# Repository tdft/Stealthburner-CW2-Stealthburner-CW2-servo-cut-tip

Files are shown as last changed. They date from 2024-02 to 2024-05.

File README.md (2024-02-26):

# Stealthburner-CW2-Stealthburner-CW2-servo-cut-tip # klipper # mmu # ervf v2 #
Cutting tip of Stealthburner-CW2 servo steering gear

bilibili UID:450728302

by 3D造物主

1708151775972fbb961577cd52aac32a4a684aa6e033fde65

新版Happy-Hare可根据官方教程修改 https://github.com/moggieuk/Happy-Hare 进行修改

具体测试见哔哩哔哩【voron sb头舵机切刀测试】https://www.bilibili.com/video/BV19A4m157Jf?vd_source=c7e963c712fcfe6c78b672060f20e54b

https://github.com/tdft/Stealthburner-CW2-Stealthburner-CW2-servo-cut-tip/assets/52322373/de4dca90-7167-4381-bc9b-4ff3145389e5

本人对于所有事故不承担任何责任（包括但不限于触电、电器损坏等）

安装模块前务必断电拆机以免发生安全事故。

MG90S舵机待验证！！！

MG90S舵机待验证！！！

MG90S舵机待验证！！！
    
!!!!!!!!!!!!!!!!!!!!!!!!!!!!!!!!!!!!!!!
切刀臂不要加装弹簧，切刀回位依靠舵机！！！
！！！！！！！！！！！！！！！！！！！！！
    
安装前准备：

M3热熔螺母3*4*5若干

M3*12螺丝一颗

ES08MD舵机*1（MG90S）

电烙铁

cw2螺丝套装

舵机线预留100mm+

调试前拆掉切刀撞块，以免损坏部件


mmu/base/mmu_filametrix.cfg内的如下需根据机器大小、清理位置进行修改，仅参考

    ######################################
    
    #这应设置为从内部喷嘴尖端到切割刀片的距离，并用于上的计算
    #灯丝末端的最终位置(输出_停止_位置)和剩余灯丝片段大小(输出_剩余_灯丝)
    #供快乐野兔使用
    variable_blade_pos:37.5
    
    #切割前缩回的距离，这减少了浪费的细丝，但可能会造成堵塞
    #如果设置太大和/或轴端组件中有间隙
    #这必须小于“balde_pos”，即从喷嘴到刀具的距离
    variable_retract_length:32.5
    
    #销的位置，这应该是刀具架切刀时的位置
    #轻轻碰一下针
    variable_pin_loc_x:165 #22
    variable_pin_loc_y: 305
    
    #切割时的开始和结束位置
    #具体来说，不是通过移动到上面的销位置来进行切割，
    #我们沿X轴留有一个小的安全余量，以避免旅行时刮伤销
    #这也应该提供一小段距离，以便在按压销时产生一些动量
    variable_pin_park_x_dist:0 #9
    
    #刀具完全压缩时刀具架的位置
    #应留有较小的净空(例如，应稍大于0，或xmin值),以避免撞击工具架或台架
    variable_pin_loc_x_compressed: 165  #1
    
    #切削后缩回长度和速度，以便刀具可以回到原点位置
    variable_rip_length: 1			#收回以帮助手柄减压的距离(> = 0)
    variable_rip_speed: 750
    
    #将剩余的尖端从冷端推入热端。不能大于“回缩_长度”
    variable_pushback_length: 10
    variable_pushback_dwell_time: 0		#推后停留的时间
    ##########################################################################

安装

##########################################################################
1.
安装模块后需将mmu/base/mmu_hardware.cfg中的FILAMETRIX切丝机的可选龙门伺服系统[mmu_servo mmu_gantry_servo]
打开
参数仅供ES08MD数字舵机使用！！！！
    #用于FILAMETRIX切丝机的可选龙门伺服系统-
    #基本伺服PWM设置。如果这些值改变，那么为不同位置定义的角度也将改变
    #
    #仅当有机架伺服时取消注释
    
    #######################################
    
      [mmu_servo mmu_gantry_servo]
    pin:  EBBCan:PB9
    maximum_servo_angle: 180
    minimum_pulse_width: 0.0005
    maximum_pulse_width: 0.0025
    initial_angle: 130
    #######################################

2.
打开mmu/base/mmu_filametrix.cfg，启用机架伺服选项
    
    ########################################
    
    #如果安装了机架伺服选项，启用伺服并设置上下角度位置
    variable_gantry_servo_enabled: 1
    variable_gantry_servo_down_angle: -5  #即切料
    variable_gantry_servo_up_angle: 130
    
    ########################################

*3.选用
(直接复制替换掉mmu/base/mmu_filametrix.cfg内的参数)
    
    ########################################
    
    [gcode_macro _FILAMETRIX_GANTRY_SERVO_DOWN]
    description: Operate optional gantry servo operated pin
    gcode:
        {% if printer['gcode_macro _MMU_CUT_TIP']['gantry_servo_enabled'] > 0 %}
            {% set ANGLE = printer['gcode_macro _MMU_CUT_TIP']['gantry_servo_down_angle'] | float %}
            status_busy
            SET_SERVO SERVO=mmu_gantry_servo ANGLE={ANGLE}
            G4 P500
            _FILAMETRIX_GANTRY_SERVO_UP
            G4 P300
            SET_SERVO SERVO=mmu_gantry_servo ANGLE={ANGLE}
            G4 P200
            _FILAMETRIX_GANTRY_SERVO_UP
            SET_SERVO SERVO=mmu_gantry_servo ANGLE={ANGLE}
            G4 P600
            status_part_ready
        {% endif %}
    
    [gcode_macro _FILAMETRIX_GANTRY_SERVO_UP]
    description: Operate optional gantry servo operated pin
    gcode:
        {% if printer['gcode_macro _MMU_CUT_TIP']['gantry_servo_enabled'] > 0 %}
            {% set ANGLE = printer['gcode_macro _MMU_CUT_TIP']['gantry_servo_up_angle'] | float %}
            SET_SERVO SERVO=mmu_gantry_servo ANGLE={ANGLE}
        {% endif %}
        
    ########################################

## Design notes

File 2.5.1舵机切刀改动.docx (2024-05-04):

2.5.1

mmu/base/mmu_cut_tip.cfg内

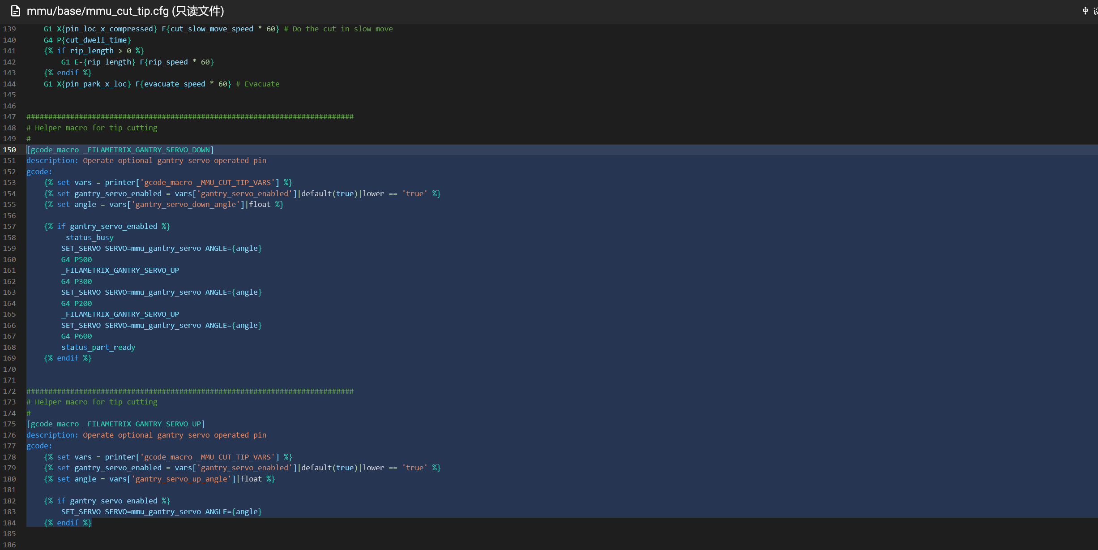
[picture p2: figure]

[gcode_macro _FILAMETRIX_GANTRY_SERVO_DOWN]

description: Operate optional gantry servo operated pin

gcode:

{% set vars = printer['gcode_macro _MMU_CUT_TIP_VARS'] %}

{% set gantry_servo_enabled = vars['gantry_servo_enabled']|default(true)|lower == 'true' %}

{% set angle = vars['gantry_servo_down_angle']|float %}

{% if gantry_servo_enabled %}

status_busy

SET_SERVO SERVO=mmu_gantry_servo ANGLE={angle}

G4 P500

_FILAMETRIX_GANTRY_SERVO_UP

G4 P300

SET_SERVO SERVO=mmu_gantry_servo ANGLE={angle}

G4 P200

_FILAMETRIX_GANTRY_SERVO_UP

SET_SERVO SERVO=mmu_gantry_servo ANGLE={angle}

G4 P600

status_part_ready

{% endif %}

# Helper macro for tip cutting

[gcode_macro _FILAMETRIX_GANTRY_SERVO_UP]

description: Operate optional gantry servo operated pin

gcode:

{% set vars = printer['gcode_macro _MMU_CUT_TIP_VARS'] %}

{% set gantry_servo_enabled = vars['gantry_servo_enabled']|default(true)|lower == 'true' %}

{% set angle = vars['gantry_servo_up_angle']|float %}

{% if gantry_servo_enabled %}

SET_SERVO SERVO=mmu_gantry_servo ANGLE={angle}

{% endif %}

mmu/base/mmu_hardware.cfg内

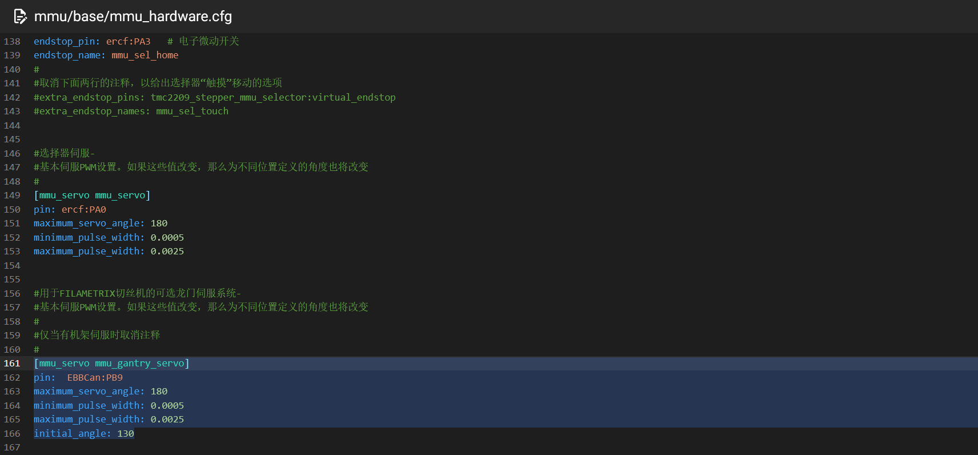
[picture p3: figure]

[mmu_servo mmu_gantry_servo]

pin: EBBCan:PB9 #按照自己舵机切刀引脚进行配置

maximum_servo_angle: 180

minimum_pulse_width: 0.0005

maximum_pulse_width: 0.0025

initial_angle: 130

mmu/base/mmu_parameters.cfg内

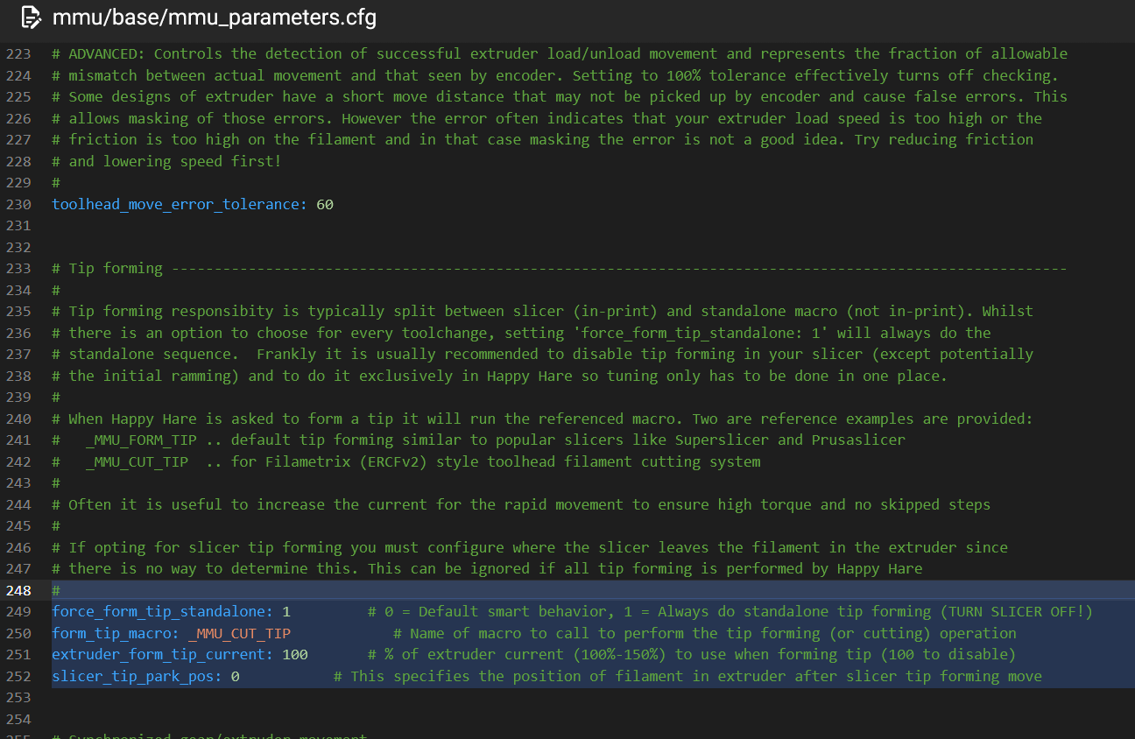
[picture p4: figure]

force_form_tip_standalone: 1 # 0 = Default smart behavior, 1 = Always do standalone tip forming (TURN SLICER OFF!)

form_tip_macro: _MMU_CUT_TIP # Name of macro to call to perform the tip forming (or cutting) operation

extruder_form_tip_current: 100 # % of extruder current (100%-150%) to use when forming tip (100 to disable)

slicer_tip_park_pos: 0 # This specifies the position of filament in extruder after slicer tip forming move

mmu/base/mmu_macro_vars.cfg内根据自己机器配置[gcode_macro _MMU_CUT_TIP_VARS]

参考：

[gcode_macro _MMU_CUT_TIP_VARS]

description: Happy Hare toolhead tip cutting macro configuration variables

gcode: # Leave empty

# Whether the toolhead tip cutting macro will return toolhead to initial

# position (usually wipetower) after the cut is complete. If using parking

# logic you may want to disable this and set 'park_after_form_tip: True'

variable_restore_position : True ; True = return to initial position, False = don't return

# Distance from the internal nozzle tip to the cutting blade. This dimension

# is based on your toolhead and should not be used for tuning

variable_blade_pos : 37.5 ; Distance in mm from internal nozzle tip

# Distance to retract prior to making the cut, this reduces wasted filament

# (left behind in extruder) but might cause clog if set too large and/or if

# there are gaps in the hotend assembly. This must be less than 'blade_pos'

variable_retract_length : 31.5 ; (5mm less than 'blade_pos' is a good starting point)

# Whether to perform a simple tip forming move after the initial retraction

# Enabling this adds some time to the cutting but gives some additional cooling

# time of molten filament and avoids potential clogging on some hotends

variable_simple_tip_forming : 1 ; True = Perform simple tip forming, False = skip

# This should be the position of the toolhead where the cutter arm just

# lightly touches the depressor pin

variable_pin_loc_xy : 280, 304 ; x,y coordinates of depressor pin

# This distance is added to 'pin_loc_x' to determine the starting position

# and to create a small saftely distance that aids in generating momentum

variable_pin_park_x_dist : 0 ; Distance in mm

# Position of the toolhead when the cutter is fully compressed. Should leave

# a small headroom (should be a bit larger than 0, or whatever xmin is) to

# avoid banging the toolhead or gantry

variable_pin_loc_x_compressed : 280 ; x coordinate

# Retract length and speed after the cut so that the cutter blade doesn't

# get stuck on return to origin position

variable_rip_length : 1 ; Distance in mm to retract to aid lever decompression (>= 0)

variable_rip_speed : 12 ; Speed mm/s

# Pushback of the remaining tip from the cold end into the hotend. This does

# not have to push back all the way, just sufficient to ensure filament

# fragment stays in hot end. Cannot be larger than 'retract_length'

variable_pushback_length : 10 ; Distance in mm

variable_pushback_dwell_time : 0 ; Time in ms to dwell after the pushback

# Speed related settings for tip cutting

# Note that if the cut speed is too fast, the steppers can lose steps.

# Therefore, for a cut:

# - We first make a fast move to accumulate some momentum and get the cut

# blade to the initial contact with the filament

# - We then make a slow move for the actual cut to happen

variable_travel_speed : 166 ; Speed mm/s

variable_cut_fast_move_speed : 33 ; Speed mm/s

variable_cut_slow_move_speed : 8 ; Speed mm/s

variable_evacuate_speed : 166 ; Speed mm/s

variable_cut_dwell_time : 50 ; Time in ms to dwell at the cut point

variable_cut_fast_move_fraction : 1.0 ; Fraction of the move that uses fast move

variable_extruder_move_speed : 50 ; Speed mm/s for all extruder movement

# Safety margin for fast vs slow travel. When traveling to the pin location

# we make a safer but longer move if we are closer to the pin than this

# specified margin. Usually setting these to the size of the toolhead

# (plus a small margin) should be good enough

variable_safe_margin_xy : 0, 0 ; Approx toolhead width +5mm, height +5mm)

# If gantry servo option is installed, enable the servo and set up and down

# angle positions

variable_gantry_servo_enabled : True ; True = enabled, False = disabled

variable_gantry_servo_down_angle: -5 ; Angle for when pin is deployed

variable_gantry_servo_up_angle : 130 ; Angle for when pin is retracted

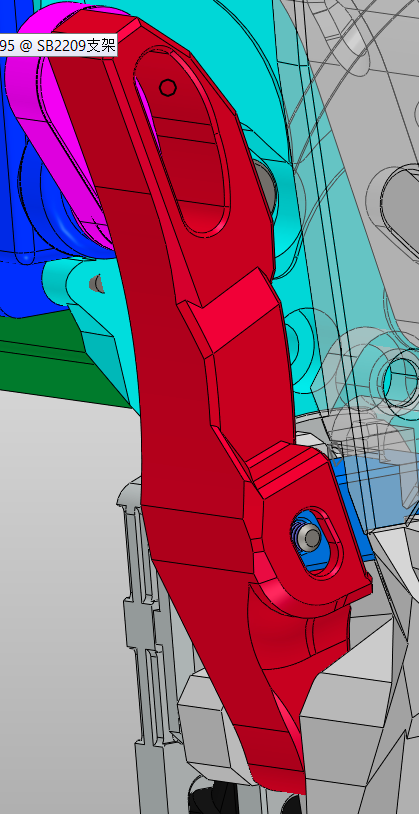
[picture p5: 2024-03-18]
stls/必打/2选1/切刀臂v2.png

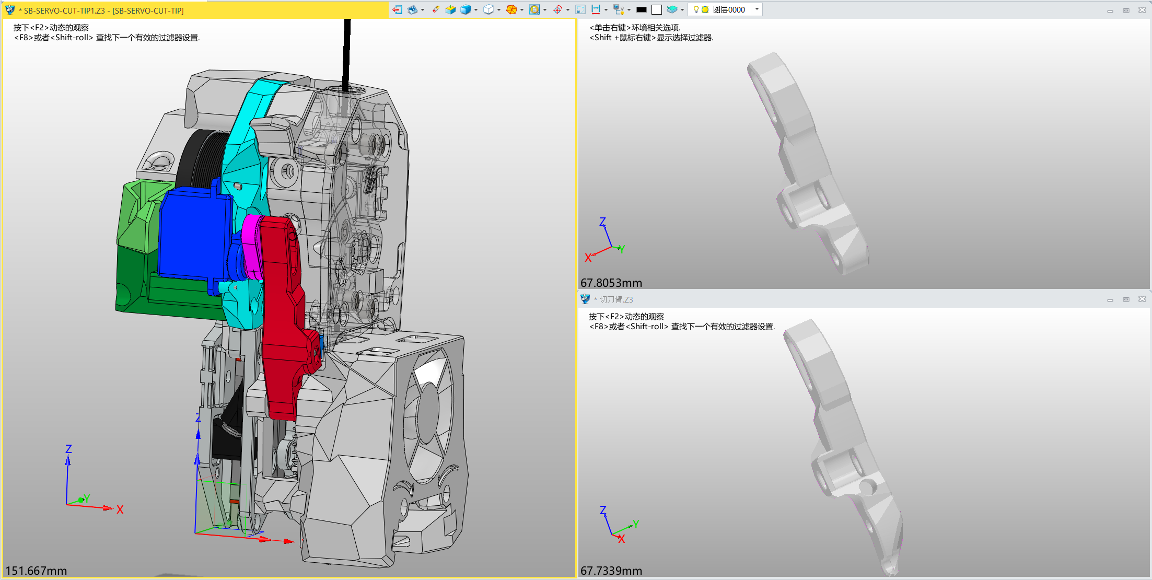
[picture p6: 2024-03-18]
jpg/v2细节对比.png

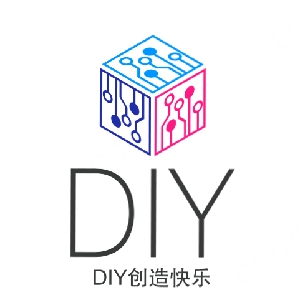
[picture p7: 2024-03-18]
jpg/bilibili 3D造物主.jpg

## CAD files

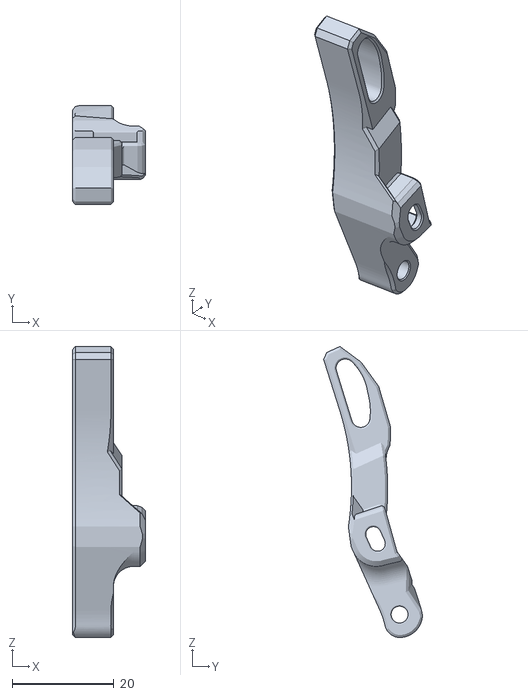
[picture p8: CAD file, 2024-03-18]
stls/必打/2选1/切刀臂v2.stl
14.3 x 19.4 x 57.1

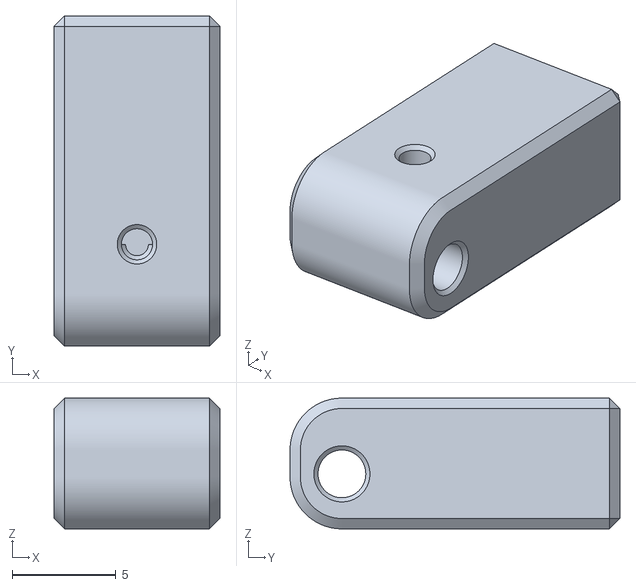
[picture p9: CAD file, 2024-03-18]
stls/必打/4mm刀头.stl
8.00 x 15.9 x 6.30

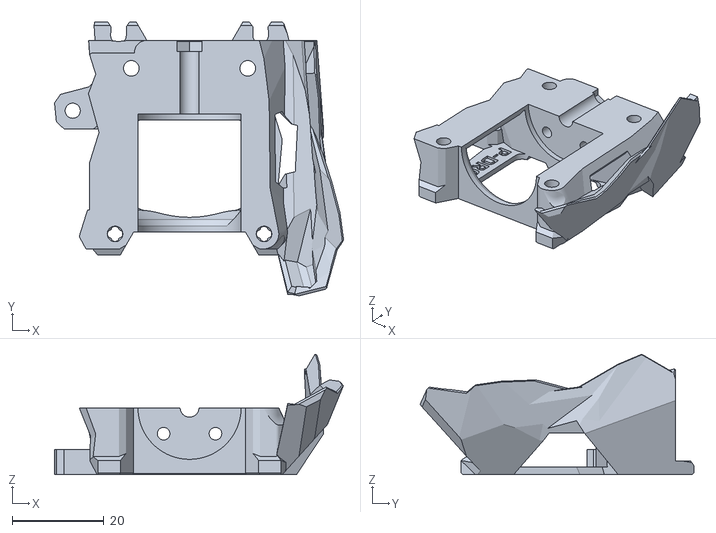
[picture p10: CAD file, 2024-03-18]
stls/根据热端打印/热端/Dragon/SB_Dragon_Cutting_Printhead_Front.stl
63.0 x 59.7 x 26.3

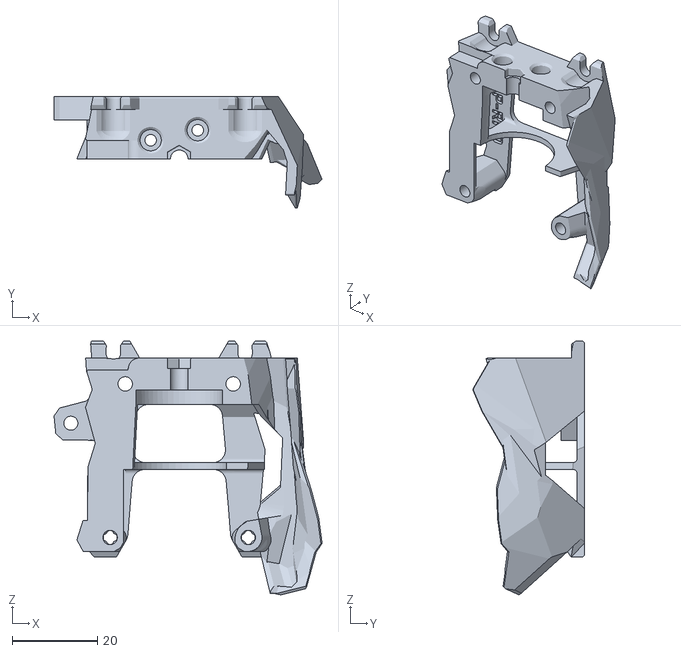
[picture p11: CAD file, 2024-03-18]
stls/根据热端打印/热端/Rapido/SB_Rapido_TH_Cutting_Printhead_Rear.stl
63.0 x 26.3 x 59.7

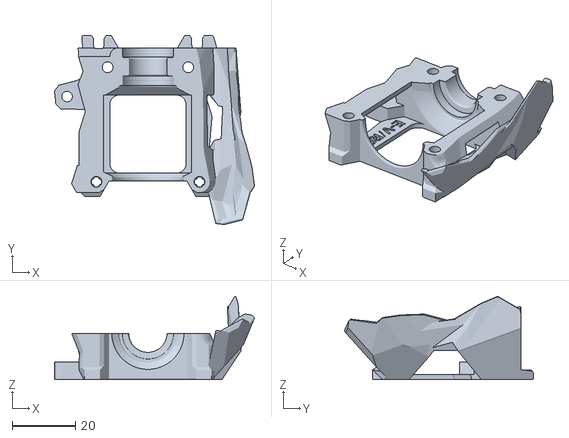
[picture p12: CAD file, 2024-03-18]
stls/根据热端打印/热端/V6_R6/SB_V6_R6_Cutting_Printhead_Back.stl
63.0 x 59.7 x 26.3

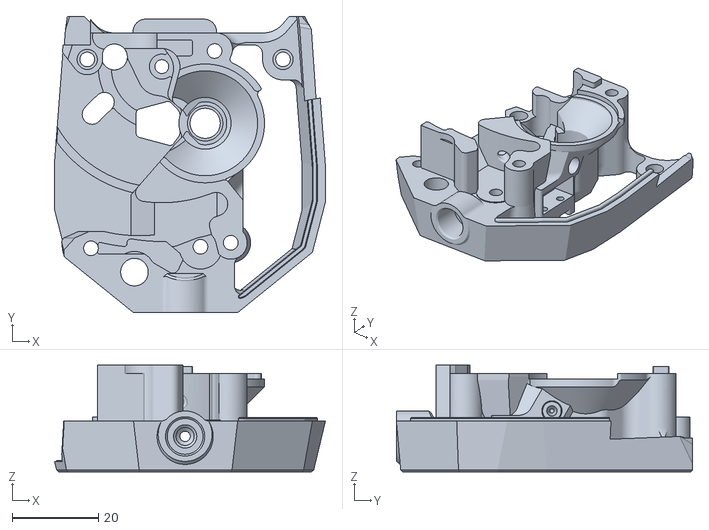
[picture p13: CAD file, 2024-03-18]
stls/耗材传感器选型/入口传感器/SB_CW2_Body.stl
62.8 x 68.7 x 24.7

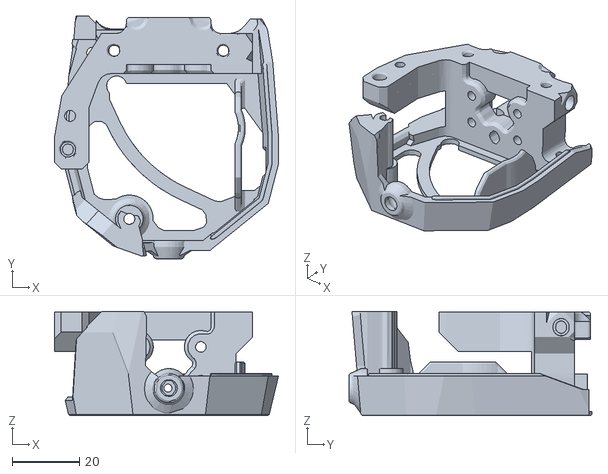
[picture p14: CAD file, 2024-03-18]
stls/耗材传感器选型/没有传感器/SB_LGX_Lite_Body.stl
66.5 x 72.1 x 31.0

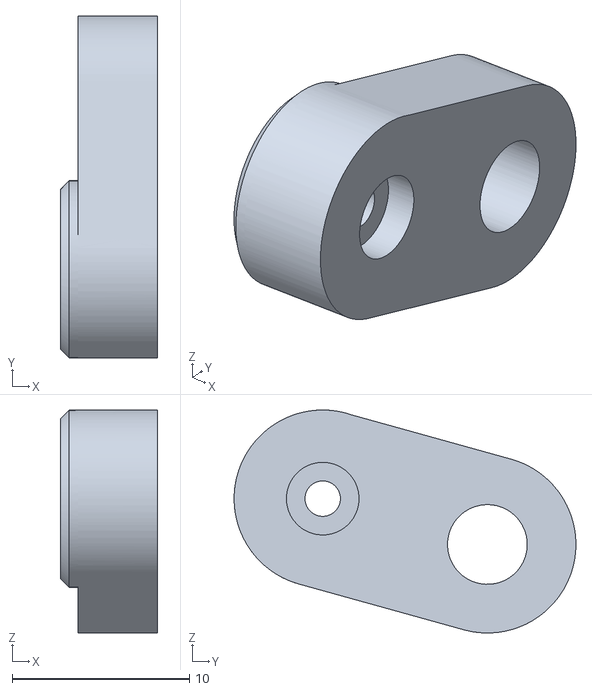
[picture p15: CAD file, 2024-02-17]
stls/舵机/ES08MD/ES08MD-舵机摇杆.stl
5.50 x 19.3 x 12.6

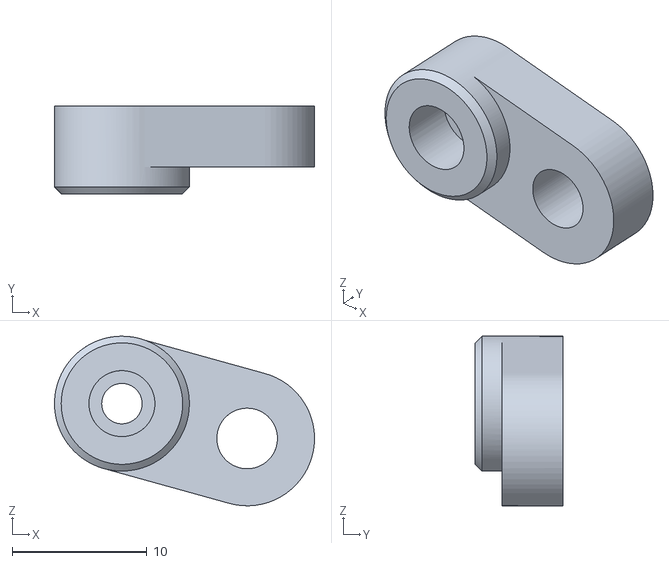
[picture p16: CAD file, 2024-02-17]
stls/舵机/MG90S/MG90S-舵机摇杆.stl
19.3 x 6.50 x 12.6

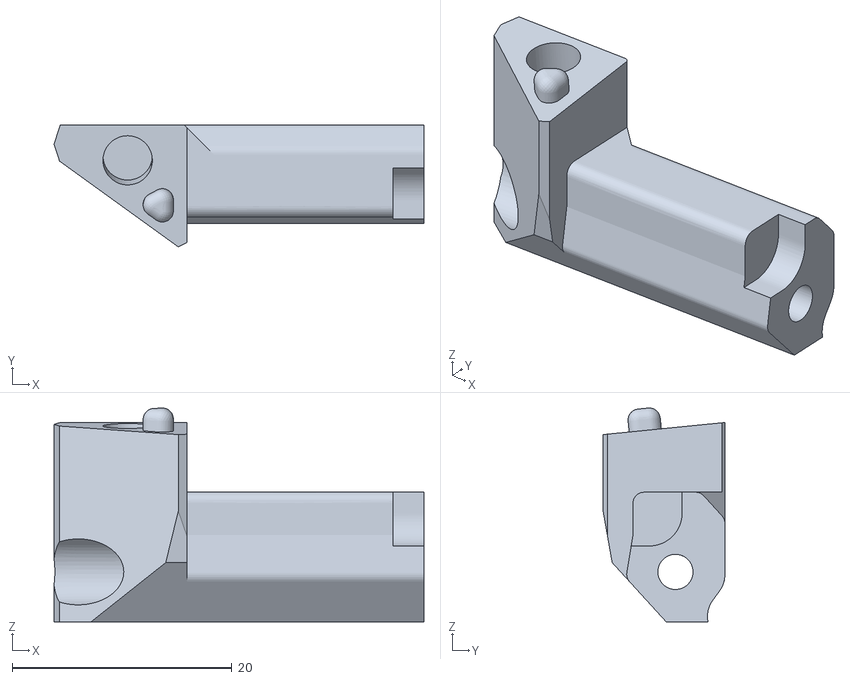
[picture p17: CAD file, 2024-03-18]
stls/选打/2.stl
33.7 x 11.1 x 19.5

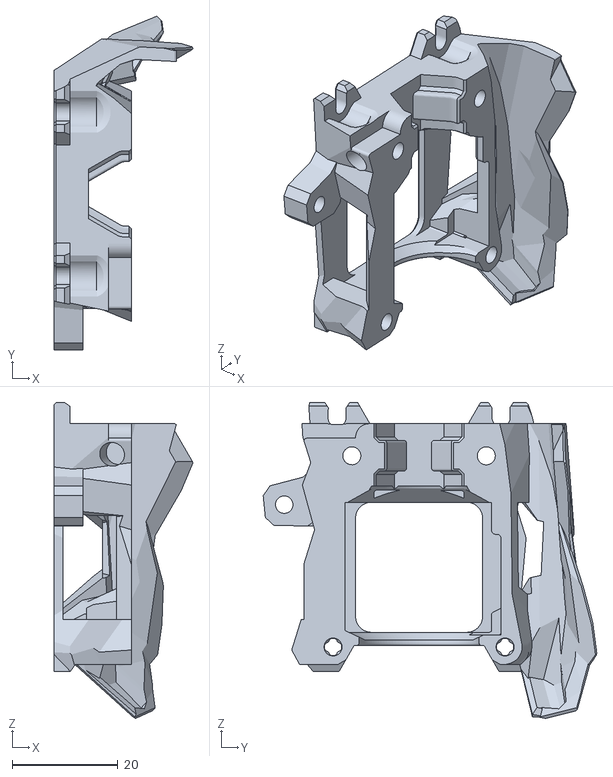
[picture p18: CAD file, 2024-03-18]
stls/根据热端打印/热端/Bambu/SB_Bambu_Cutting_Printhead_Back.stl
26.3 x 63.0 x 59.7

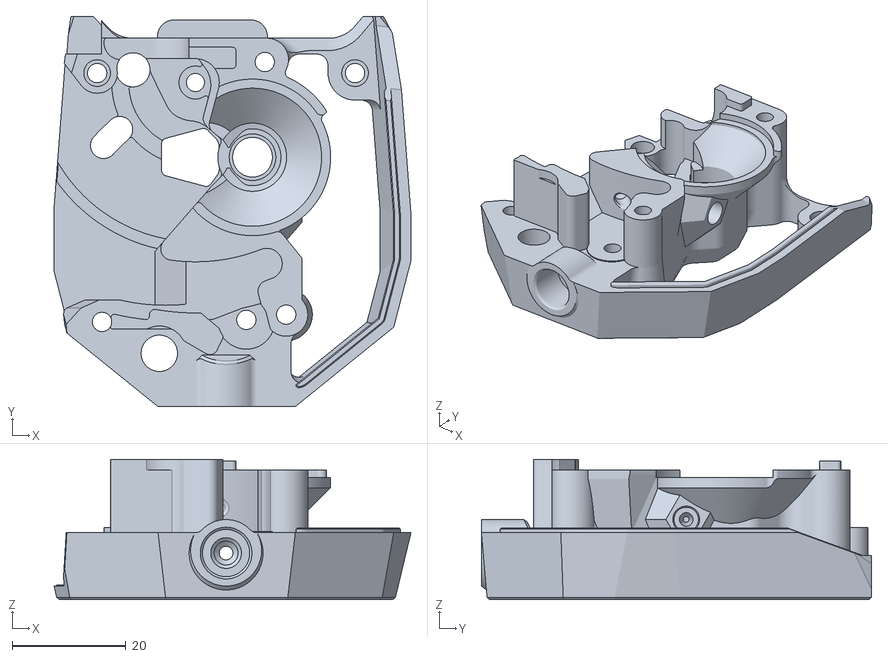
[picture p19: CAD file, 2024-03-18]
stls/耗材传感器选型/没有传感器/SB_CW2_Body.stl
62.8 x 68.7 x 24.7

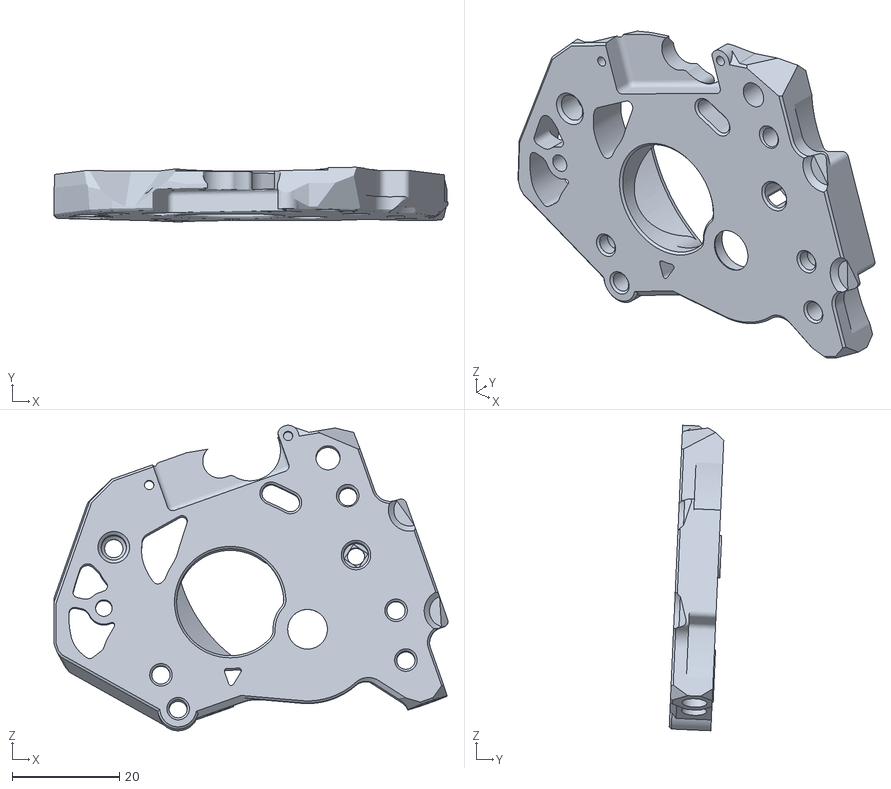
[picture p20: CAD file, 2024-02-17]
stls/舵机/ES08MD/ES08MD-CW背板.stl
73.5 x 10.2 x 57.0

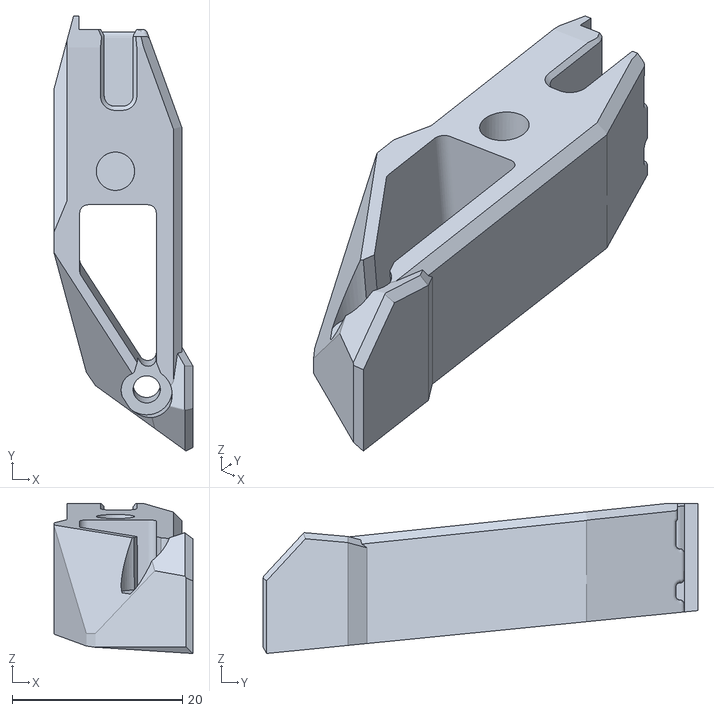
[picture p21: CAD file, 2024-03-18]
stls/选打/1.stl
16.3 x 51.1 x 17.6

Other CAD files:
stls/根据热端打印/热端/Revo/SB_Revo_Voron_Cutting_Printhead_Back.stl
stls/耗材传感器选型/工具头和入口传感器/SB_CW2_Body.stl
stls/舵机/MG90S/MG90S-CW背板.stl
stls/根据热端打印/热端/Bambu/Bambu_Adapter.stl
stls/必打/2选1/切刀臂.stl
stls/根据热端打印/热端/Bambu/Bambu_Adapter_M5_Nut.stl
stls/选打/3.stl
stls/选打/sb2209无风扇.stl

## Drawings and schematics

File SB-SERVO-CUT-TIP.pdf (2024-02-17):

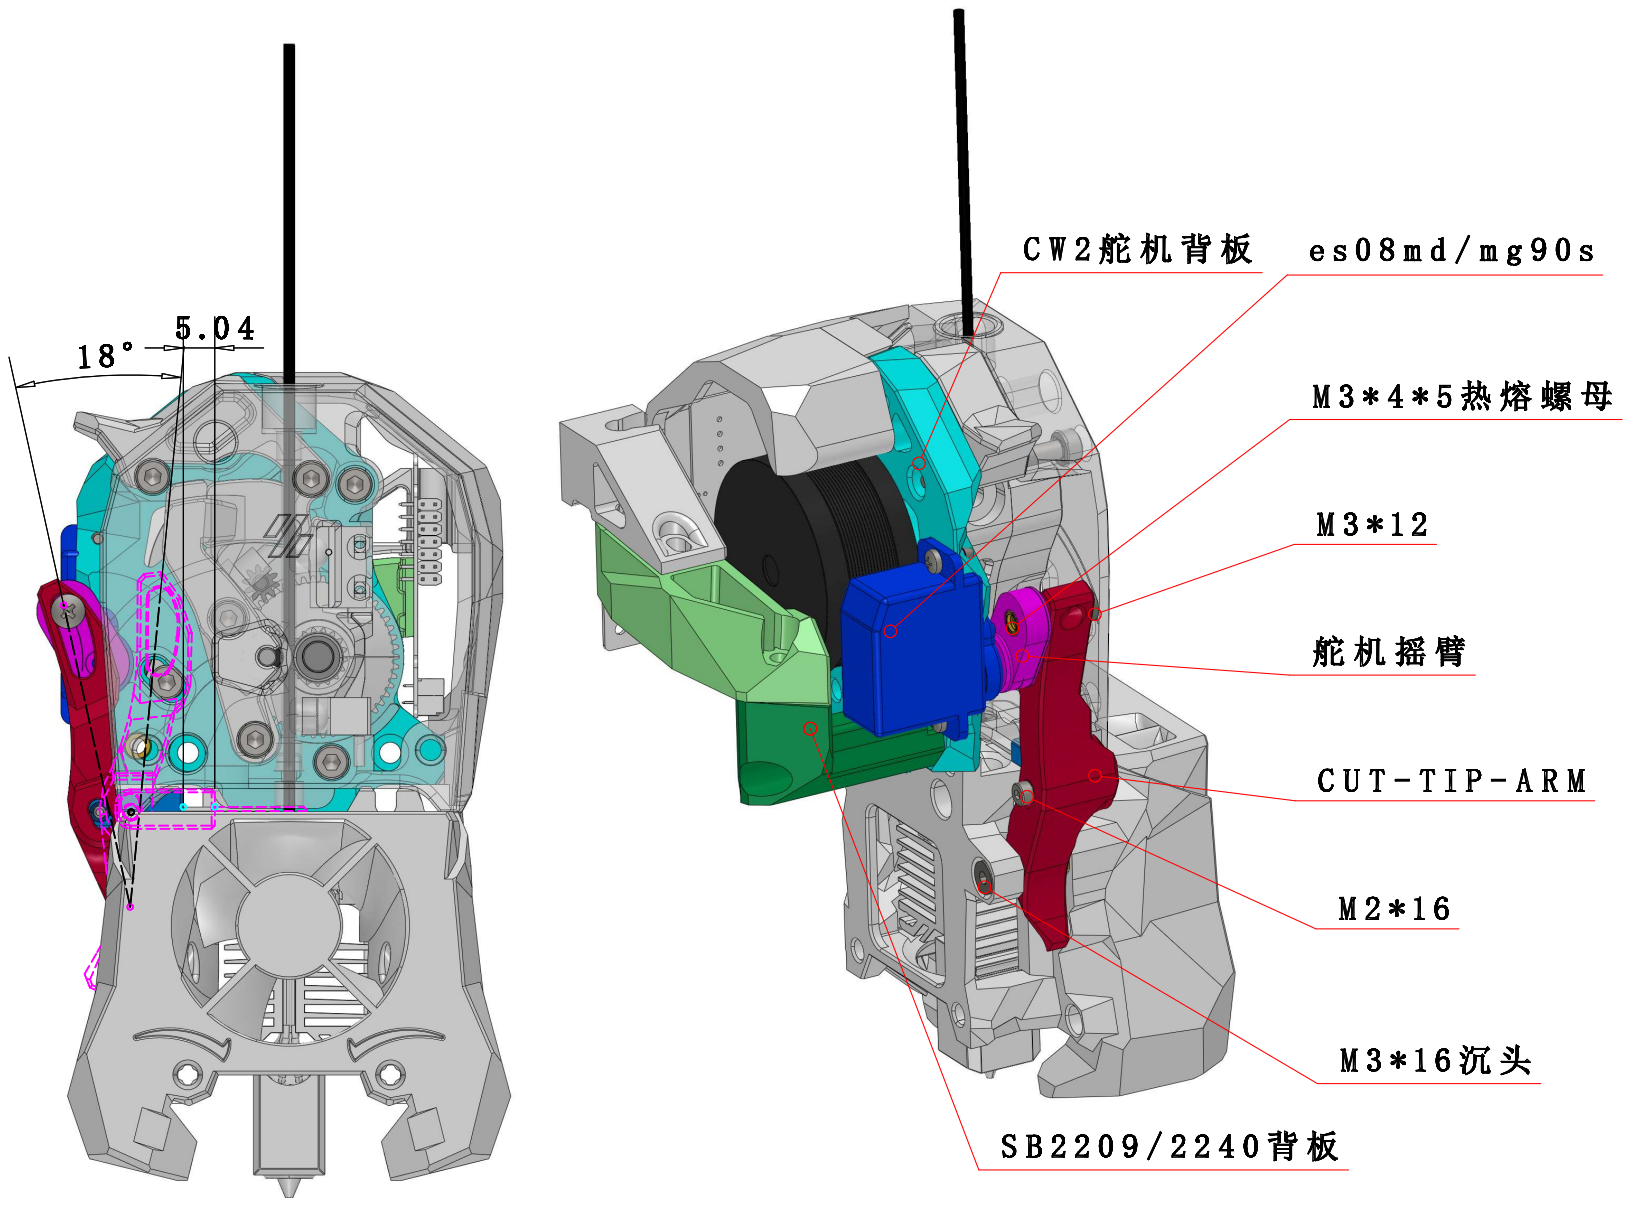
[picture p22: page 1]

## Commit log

2024-03-18 更新v2切刀臂（取消弹簧孔、切刀变得更短、优化干涉问题）
    （取消弹簧孔、切刀变得更短、优化干涉问题）
    [1.stl, 2.stl, 3.stl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]
2024-05-04 happy-hare2.5.1舵机切刀改动
    配置文件
